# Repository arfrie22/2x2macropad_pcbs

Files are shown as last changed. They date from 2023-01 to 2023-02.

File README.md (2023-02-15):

# The PCBs for the 2x2 Macropad

This is a 2x2 Macropad with per-key RGB backlighting. It uses the RP2040 microcontroller and uses a custom firmware located at [https://github.com/arfrie22/2x2macropad_firmware](https://github.com/arfrie22/2x2macropad_firmware).

The PCBs are designed in KiCad

## Features

- Custom lighting effects
- Support for normal keys and media keys
- Keys can act as a key or used for a custom macro
- Up to 4 macros per key
- Customizable timing

## Building

The interactive BOM is can be viewed [here](https://htmlpreview.github.io/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).

There are 3 pcbs in this project:

- The main pcb, which contains all of the components
- The top plate, which holds the keyswitches
- The bottom plate, which protects the components

## Info

This project was created for a workshop hosted by the UMass All Campus Makerspace. The keyboard was designed to have as many parts as I could reasonably have be though-hole, while keeping the cost relativly low.

## Pictures
Macropad forwards with no rgb
Macropad backwards with rgb
Macropad rotated with rgb

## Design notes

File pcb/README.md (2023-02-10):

# Macropad pcb

## Images

### Front

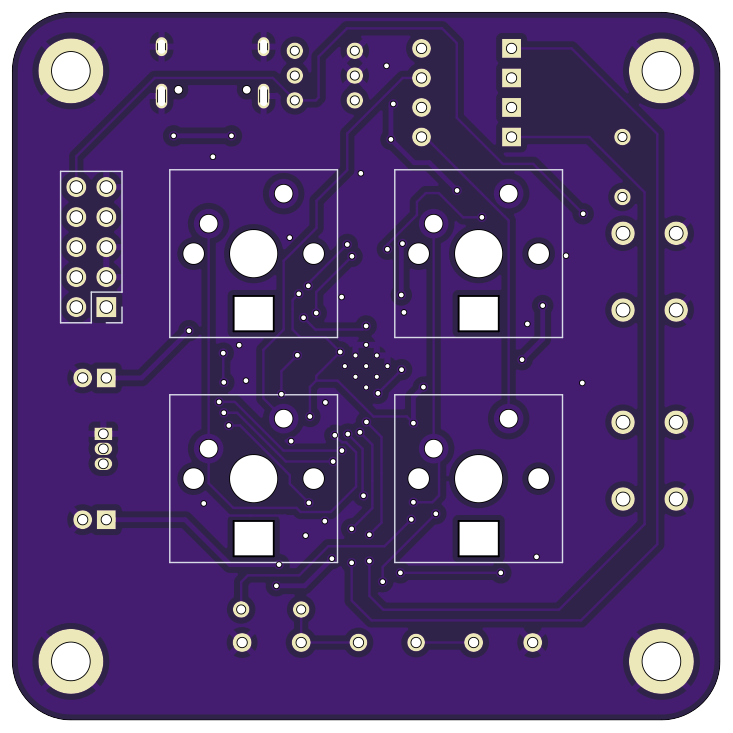
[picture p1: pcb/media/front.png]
Macropad pcb front


### Back

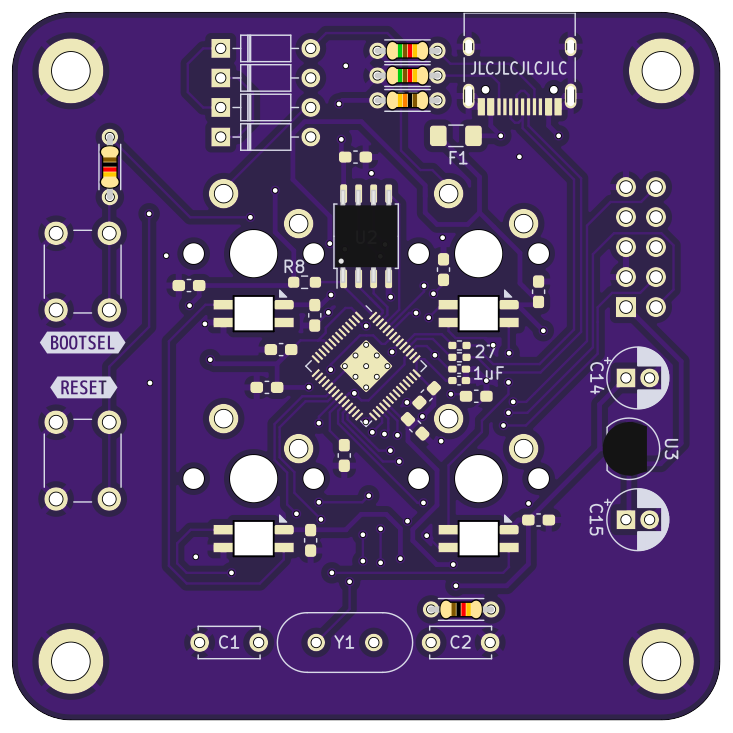
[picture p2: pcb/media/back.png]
Macropad pcb back


This is the main pcb for the 2x2 Macropad. Everything is on this pcb.
You can find the build instructions [here](https://htmlpreview.github.io/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).

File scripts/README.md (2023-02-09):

# Scripts for the project

This directory contains scripts for the project. These scripts are used to interact with kikit and pcbdraw.

## Scripts

- [plot.sh](plot.sh): Generates the images for the README.md files using pcbdraw
- [stencil.sh](stencil.sh): Generates the stencil and allignment jig files using kikit

## Dependencies

- [kikit](https://github.com/yaqwsx/KiKit)
- [pcbdraw](https://github.com/yaqwsx/PcbDraw)

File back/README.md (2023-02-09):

# Macropad back

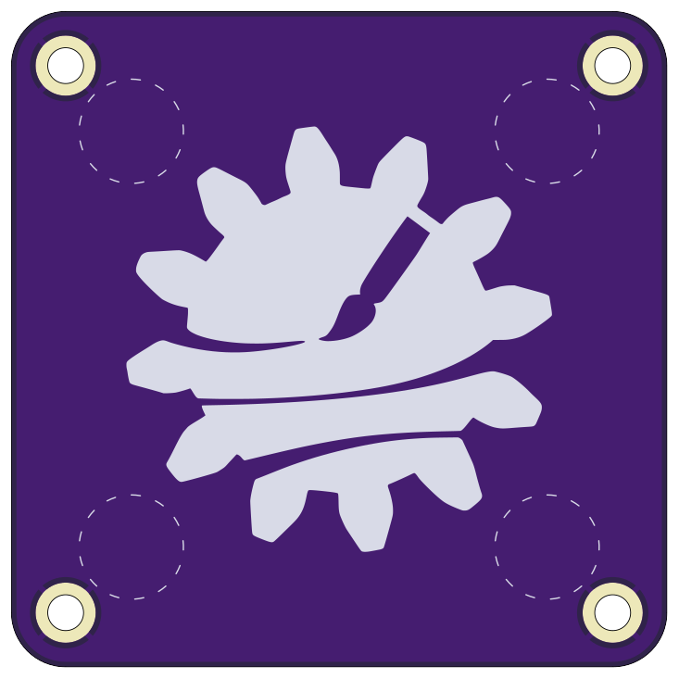
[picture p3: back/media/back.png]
Macropad back


This is the back of the macropad.

Nothing needs to be assembled

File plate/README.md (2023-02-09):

# Macropad plate

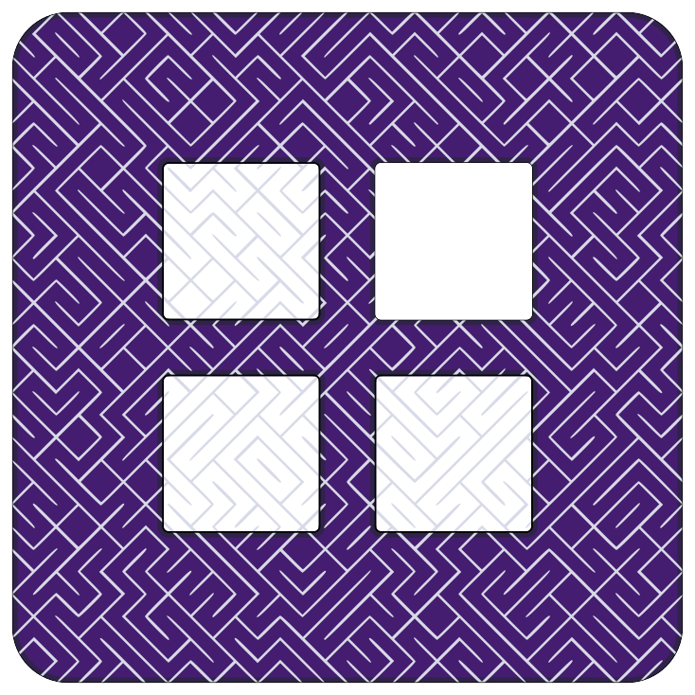
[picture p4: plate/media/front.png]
Macropad plate


This is the plate that holds the keyswitches.

Nothing needs to be assembled

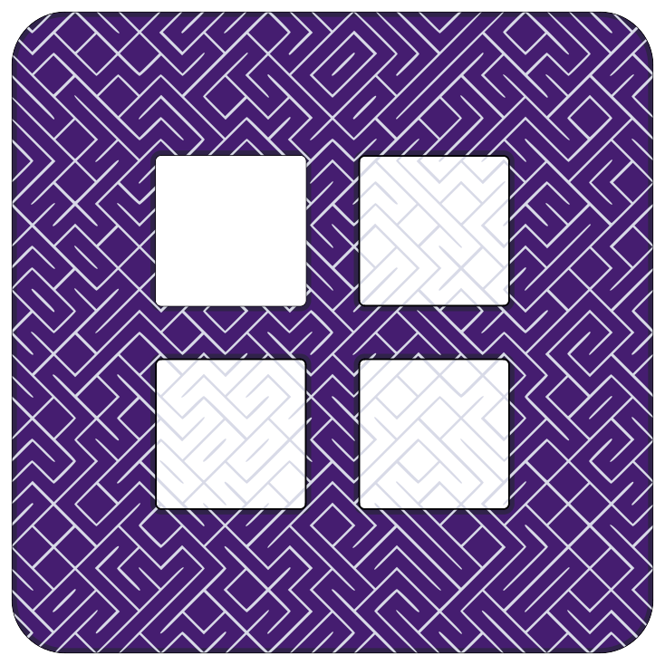
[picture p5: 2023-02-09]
plate/media/back.png

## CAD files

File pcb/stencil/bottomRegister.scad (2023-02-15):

// Generated by SolidPython 1.1.3 on 2023-02-13 22:43:17


scale(v = 0.0000010000) {
	translate(v = [-130000000, -130000000, 0]) {
		difference() {
			linear_extrude(convexity = 10, height = 2850000) {
				polygon(points = [[97000000.0000000000, 125762240.5374987423], [96996180.2977239937, 125913390.5052574873], [96984740.5116602331, 126064028.5974797755], [96965706.6532962620, 126213896.5919596255], [96939127.3132557571, 126362611.8978855163], [96905070.3446603566, 126509794.8670897037], [96863622.6899109036, 126655069.7632328868], [96814890.1587363183, 126798065.7210039198], [96758997.1580766439, 126938417.6928849071], [96696086.3744910806, 127075767.3810620308], [96626318.4099002779, 127209764.1521069556], [96549871.3715929985, 127340065.9320933074], [96466940.4175444692, 127466340.0798602998], [96377737.2582080364, 127588264.2361951321], [96282489.6160481274, 127705527.1467704773], [96181440.6441995949, 127817829.4567292184], [96074848.3057340533, 127924884.4748928398], [95962891.1387931257, 128026503.8414003402], [95886920.7662769109, 128092036.3354085833], [95886736.9051579833, 128092198.9126200974], [95759512.9314664453, 128207508.0010067970], [95759333.1155675352, 128207675.0414308310], [95733047.8039082885, 128232700.7385261506], [95732700.7385261506, 128233047.8039082885], [95707675.0414308310, 128259333.1155675352], [95707508.0010067970, 128259512.9314664453], [95592198.9126200974, 128386736.9051579833], [95592036.3354085833, 128386920.7662769109], [95568330.5419733971, 128414402.3688821197], [95568019.1661621928, 128414781.7814058512], [95545690.3857198805, 128443393.4693693072], [95545541.7746813446, 128443588.7922301888], [95443258.0611555576, 128581502.4148115218], [95443114.2883388549, 128581701.3259422630], [95422216.3128771931, 128611374.1712017059], [95421943.6253561974, 128611782.2769170254], [95402526.7999293208, 128642444.7949880213], [95402398.0494818240, 128642653.7437449545], [95314124.7588912696, 128789928.8316404969], [95314001.1750801802, 128790140.8771601319], [95296112.2765202522, 128821719.1993524879], [95295880.9034193903, 128822152.0679782331], [95279563.0276503861, 128854570.1193470657], [95279455.3777310997, 128854790.6817093194], [95206042.6301199049, 129010008.8953127414], [95205940.4254941046, 129010232.0331069976], [95191232.8837078214, 129043411.7157275826], [95191045.0532765090, 129043865.1785022765], [95177983.2772298753, 129077726.5596116930], [95177897.7645663917, 129077956.6114431173], [95120052.5648249090, 129239623.1145078689], [95119972.7236708105, 129239855.1956378073], [95108588.1803259403, 129274316.7002041638], [95108445.7014739215, 129274786.3900334090], [95098765.8171928674, 129309764.9972739518], [95098703.2653188705, 129310002.3230496645], [95056982.6943425238, 129476560.1787738949], [95056925.9855740815, 129476798.9681713581], [95048974.0800460279, 129512210.4115571678], [95048878.3249225318, 129512691.8050711304], [95042673.5549846143, 129548450.7753324807], [95042634.5663088560, 129548693.0894755274], [95017440.4160025716, 129718538.2546602637], [95017407.3857562244, 129718781.4526528269], [95012964.6992424577, 129754801.8032992482], [95012916.5900216699, 129755290.2644152492], [95010246.6897530854, 129791485.2192665190], [95010231.6397578120, 129791730.1881592423], [95001806.5435616970, 129963226.9610166550], [95001797.5099367946, 129963472.2254747003], [95000906.8279369473, 129999754.5877147764], [95000906.8279369473, 130000245.4122852236], [95001797.5099367946, 130036527.7745253295], [95001806.5435616970, 130036773.0389833748], [95010231.6397578120, 130208269.8118406534], [95010246.6897530854, 130208514.7807333767], [95012916.5900216699, 130244709.7355845422], [95012964.6992424577, 130245198.1967005432], [95017407.3857562840, 130281218.5473475605], [95017440.4160026312, 130281461.7453401238], [95042634.5663087964, 130451306.9105241001], [95042673.5549845546, 130451549.2246671468], [95048878.3249225765, 130487308.1949290484], [95048974.0800460726, 130487789.5884430110], [95056925.9855740964, 130523201.0318287015], [95056982.6943425387, 130523439.8212261647], [95098703.2653188705, 130689997.6769503355], [95098765.8171928674, 130690235.0027260482], [95108445.7014739215, 130725213.6099665910], [95108588.1803259403, 130725683.2997958362], [95119972.7236708105, 130760144.8043621927], [95120052.5648249090, 130760376.8854921311], [95177897.7645664662, 130922043.3885570914], [95177983.2772299498, 130922273.4403885156], [95191045.0532765538, 130956134.8214978576], [95191232.8837078661, 130956588.2842725515], [95205940.4254938662, 130989767.9668925107], [95206042.6301196665, 130989991.1046867669], [95279455.3777312338, 131145209.3182909787], [95279563.0276505202, 131145429.8806532323], [95295880.9034193307, 131177847.9320216924], [95296112.2765201926, 131178280.8006474376], [95314001.1750801057, 131209859.1228397787], [95314124.7588911951, 131210071.1683594137], [95402398.0494816750, 131357346.2562548220], [95402526.7999291867, 131357555.2050117552], [95421943.6253562123, 131388217.7230829597], [95422216.3128771782, 131388625.8287982643], [95443114.2883387804, 131418298.6740576476], [95443258.0611554980, 131418497.5851884037], [95545541.7746813446, 131556411.2077698112], [95545690.3857198805, 131556606.5306306928], [95568019.1661621928, 131585218.2185941488], [95568330.5419733971, 131585597.6311178803], [95592036.3354085833, 131613079.2337230891], [95592198.9126200974, 131613263.0948420167], [95707508.0010067970, 131740487.0685335547], [95707675.0414308310, 131740666.8844324648], [95732700.7385261506, 131766952.1960917115], [95733047.8039082885, 131767299.2614738494], [95759333.1155675352, 131792324.9585691690], [95759512.9314664453, 131792491.9989932030], [95886736.9051579833, 131907801.0873799026], [95886920.7662769109, 131907963.6645914167], [95962891.1387931257, 131973496.1585996598], [96074848.3057340533, 132075115.5251071602], [96181440.6441995949, 132182170.5432707816], [96282489.6160481274, 132294472.8532295227], [96377737.2582080364, 132411735.7638048679], [96466940.4175444692, 132533659.9201397002], [96549871.3715929985, 132659934.0679066926], [96626318.4099002779, 132790235.8478930444], [96696086.3744910806, 132924232.6189379692], [96758997.1580766439, 133061582.3071150929], [96814890.1587363183, 133201934.2789960802], [96863622.6899109036, 133344930.2367671132], [96905070.3446603566, 133490205.1329102963], [96939127.3132557571, 133637388.1021144837], [96965706.6532962620, 133786103.4080403745], [96984740.5116602331, 133935971.4025202245], [96996180.2977239937, 134086609.4947425127], [97000000.0000000000, 134237759.4625012577], [97000000.0000000000, 154983190.8553380966], [97000000.6278632730, 154983302.9127845466], [97000374.8108018786, 155016692.8798815608], [97000376.6943128705, 155016804.9232566953], [97006905.2673033178, 155308054.7890836596], [97006909.4315571487, 155308196.0209841728], [97008447.5638170391, 155350270.1459383667], [97008453.7231172323, 155350411.3049046695], [97014116.2972820103, 155462067.7529985011], [97014123.5145155489, 155462194.2235107720], [97016512.7726620734, 155499865.7805950046], [97016521.5913657695, 155499992.1495365798], [97032871.7751336396, 155714693.9899461865], [97032882.1938923448, 155714820.2370388508], [97036225.0080600977, 155752419.1779938638], [97036237.0252019465, 155752545.2829788327], [97047769.4693838507, 155865953.0643368661], [97047783.0829804540, 155866079.0069782436], [97052077.3075863123, 155903581.1989485323], [97052092.5154531300, 155903706.9590364993], [97079296.1836424470, 156117305.1079567373], [97079312.9833390564, 156117430.6653106809], [97084555.8621373177, 156154812.0375349820], [97084574.2509679347, 156154937.3720068634], [97101835.9032062441, 156267615.4865793884], [97101855.8782199919, 156267740.5780569613], [97108044.0460721850, 156304977.1373250484], [97108065.6040637344, 156305101.9657350183], [97146052.9252479672, 156517048.1197777987], [97146076.0627579242, 156517172.6650891006], [97153205.5477924496, 156554240.5111387968], [97153230.2611079514, 156554364.7533657849], [97176176.8109884113, 156666023.9580457509], [97176203.0961437374, 156666147.8772514462], [97184269.3223042786, 156703023.2181047499], [97184297.1750815213, 156703146.7944040000], [97232970.6363524497, 156912896.8908343911], [97233000.0522820652, 156913020.1043970287], [97241997.8422666490, 156949679.2716405690], [97242028.8166283220, 156949802.1026946902], [97270601.3606869876, 157060155.7699077129], [97270633.8885102868, 157060278.1987427473], [97280557.4670922011, 157096697.6627095640], [97280591.5431574434, 157096819.6696794927], [97339826.2004377544, 157303835.2830067873], [97339861.8192767799, 157303956.8485333025], [97350704.8170139790, 157340113.2334156036], [97350741.9729110748, 157340234.3379912674], [97384867.1658362597, 157448999.1914533377], [97384905.8528290689, 157449119.8156446218], [97396661.3101493269, 157484989.9144860506], [97396701.5220298022, 157485110.0389365256], [97466345.3208038956, 157688859.7630508542],
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

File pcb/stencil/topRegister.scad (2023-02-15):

// Generated by SolidPython 1.1.3 on 2023-02-13 22:43:01


scale(v = 0.0000010000) {
	translate(v = [-130000000, -130000000, 0]) {
		difference() {
			linear_extrude(convexity = 10, height = 2850000) {
				polygon(points = [[163000000.0000000000, 125762240.5374987423], [163003819.7022759914, 125913390.5052574873], [163015259.4883397818, 126064028.5974797755], [163034293.3467037380, 126213896.5919596255], [163060872.6867442429, 126362611.8978855163], [163094929.6553396583, 126509794.8670897037], [163136377.3100891113, 126655069.7632328868], [163185109.8412636817, 126798065.7210039198], [163241002.8419233561, 126938417.6928849071], [163303913.6255089045, 127075767.3810620308], [163373681.5900997221, 127209764.1521069556], [163450128.6284070015, 127340065.9320933074], [163533059.5824555159, 127466340.0798602998], [163622262.7417919636, 127588264.2361951321], [163717510.3839518726, 127705527.1467704773], [163818559.3558003902, 127817829.4567292184], [163925151.6942659616, 127924884.4748928398], [164037108.8612068892, 128026503.8414003402], [164113079.2337231040, 128092036.3354085833], [164113263.0948420167, 128092198.9126200974], [164240487.0685335398, 128207508.0010067970], [164240666.8844324648, 128207675.0414308310], [164266952.1960917115, 128232700.7385261506], [164267299.2614738345, 128233047.8039082885], [164292324.9585691690, 128259333.1155675352], [164292491.9989932179, 128259512.9314664453], [164407801.0873799026, 128386736.9051579833], [164407963.6645914316, 128386920.7662769109], [164431669.4580265880, 128414402.3688821197], [164431980.8338378072, 128414781.7814058512], [164454309.6142801046, 128443393.4693693072], [164454458.2253186703, 128443588.7922301888], [164556741.9388444424, 128581502.4148115218], [164556885.7116611600, 128581701.3259422630], [164577783.6871228218, 128611374.1712017059], [164578056.3746438026, 128611782.2769170254], [164597473.2000706792, 128642444.7949880213], [164597601.9505181909, 128642653.7437449545], [164685875.2411087155, 128789928.8316404969], [164685998.8249198198, 128790140.8771601319], [164703887.7234797478, 128821719.1993524879], [164704119.0965806246, 128822152.0679782331], [164720436.9723496139, 128854570.1193470657], [164720544.6222689152, 128854790.6817093194], [164793957.3698800802, 129010008.8953127414], [164794059.5745058954, 129010232.0331069976], [164808767.1162921786, 129043411.7157275826], [164808954.9467234910, 129043865.1785022765], [164822016.7227701247, 129077726.5596116930], [164822102.2354336083, 129077956.6114431173], [164879947.4351750910, 129239623.1145078689], [164880027.2763291895, 129239855.1956378073], [164891411.8196740746, 129274316.7002041638], [164891554.2985260785, 129274786.3900334090], [164901234.1828071475, 129309764.9972739518], [164901296.7346811295, 129310002.3230496645], [164943017.3056574762, 129476560.1787738949], [164943074.0144259334, 129476798.9681713581], [164951025.9199539721, 129512210.4115571678], [164951121.6750774682, 129512691.8050711304], [164957326.4450153708, 129548450.7753324807], [164957365.4336911440, 129548693.0894755274], [164982559.5839974284, 129718538.2546602637], [164982592.6142437756, 129718781.4526528269], [164987035.3007575274, 129754801.8032992482], [164987083.4099783301, 129755290.2644152492], [164989753.3102469146, 129791485.2192665190], [164989768.3602421880, 129791730.1881592423], [164998193.4564383030, 129963226.9610166550], [164998202.4900631905, 129963472.2254747003], [164999093.1720630527, 129999754.5877147764], [164999093.1720630527, 130000245.4122852236], [164998202.4900631905, 130036527.7745253295], [164998193.4564383030, 130036773.0389833748], [164989768.3602421880, 130208269.8118406534], [164989753.3102469146, 130208514.7807333767], [164987083.4099783301, 130244709.7355845422], [164987035.3007575274, 130245198.1967005432], [164982592.6142437160, 130281218.5473475605], [164982559.5839973688, 130281461.7453401238], [164957365.4336912036, 130451306.9105241001], [164957326.4450154305, 130451549.2246671468], [164951121.6750774384, 130487308.1949290484], [164951025.9199539423, 130487789.5884430110], [164943074.0144259036, 130523201.0318287015], [164943017.3056574464, 130523439.8212261647], [164901296.7346811295, 130689997.6769503355], [164901234.1828071475, 130690235.0027260482], [164891554.2985260785, 130725213.6099665910], [164891411.8196740746, 130725683.2997958362], [164880027.2763291895, 130760144.8043621927], [164879947.4351750910, 130760376.8854921311], [164822102.2354335189, 130922043.3885570914], [164822016.7227700353, 130922273.4403885156], [164808954.9467234612, 130956134.8214978576], [164808767.1162921190, 130956588.2842725515], [164794059.5745061338, 130989767.9668925107], [164793957.3698803186, 130989991.1046867669], [164720544.6222687662, 131145209.3182909787], [164720436.9723494649, 131145429.8806532323], [164704119.0965806842, 131177847.9320216924], [164703887.7234798074, 131178280.8006474376], [164685998.8249198794, 131209859.1228397787], [164685875.2411088049, 131210071.1683594137], [164597601.9505183101, 131357346.2562548220], [164597473.2000707984, 131357555.2050117552], [164578056.3746438026, 131388217.7230829597], [164577783.6871228218, 131388625.8287982643], [164556885.7116612196, 131418298.6740576476], [164556741.9388445020, 131418497.5851884037], [164454458.2253186703, 131556411.2077698112], [164454309.6142801046, 131556606.5306306928], [164431980.8338378072, 131585218.2185941488], [164431669.4580265880, 131585597.6311178803], [164407963.6645914316, 131613079.2337230891], [164407801.0873799026, 131613263.0948420167], [164292491.9989932179, 131740487.0685335547], [164292324.9585691690, 131740666.8844324648], [164267299.2614738345, 131766952.1960917115], [164266952.1960917115, 131767299.2614738494], [164240666.8844324648, 131792324.9585691690], [164240487.0685335398, 131792491.9989932030], [164113263.0948420167, 131907801.0873799026], [164113079.2337231040, 131907963.6645914167], [164037108.8612068892, 131973496.1585996598], [163925151.6942659616, 132075115.5251071602], [163818559.3558003902, 132182170.5432707816], [163717510.3839518726, 132294472.8532295227], [163622262.7417919636, 132411735.7638048679], [163533059.5824555159, 132533659.9201397002], [163450128.6284070015, 132659934.0679066926], [163373681.5900997221, 132790235.8478930444], [163303913.6255089045, 132924232.6189379692], [163241002.8419233561, 133061582.3071150929], [163185109.8412636817, 133201934.2789960802], [163136377.3100891113, 133344930.2367671132], [163094929.6553396583, 133490205.1329102963], [163060872.6867442429, 133637388.1021144837], [163034293.3467037380, 133786103.4080403745], [163015259.4883397818, 133935971.4025202245], [163003819.7022759914, 134086609.4947425127], [163000000.0000000000, 134237759.4625012577], [163000000.0000000000, 154983190.8553380966], [162999999.3721367121, 154983302.9127845466], [162999625.1891981363, 155016692.8798815608], [162999623.3056871295, 155016804.9232566953], [162993094.7326966822, 155308054.7890836596], [162993090.5684428513, 155308196.0209841728], [162991552.4361829758, 155350270.1459383667], [162991546.2768827677, 155350411.3049046695], [162985883.7027179897, 155462067.7529985011], [162985876.4854844511, 155462194.2235107720], [162983487.2273379266, 155499865.7805950046], [162983478.4086342454, 155499992.1495365798], [162967128.2248663604, 155714693.9899461865], [162967117.8061076403, 155714820.2370388508], [162963774.9919399023, 155752419.1779938638], [162963762.9747980535, 155752545.2829788327], [162952230.5306161642, 155865953.0643368661], [162952216.9170195460, 155866079.0069782436], [162947922.6924136877, 155903581.1989485323], [162947907.4845468700, 155903706.9590364993], [162920703.8163575530, 156117305.1079567373], [162920687.0166609287, 156117430.6653106809], [162915444.1378626823, 156154812.0375349820], [162915425.7490320802, 156154937.3720068634], [162898164.0967937708, 156267615.4865793884], [162898144.1217800081, 156267740.5780569613], [162891955.9539278150, 156304977.1373250484], [162891934.3959362507, 156305101.9657350183], [162853947.0747520328, 156517048.1197777987], [162853923.9372420907, 156517172.6650891006], [162846794.4522075653, 156554240.5111387968], [162846769.7388920486, 156554364.7533657849], [162823823.1890115738, 156666023.9580457509], [162823796.9038562775, 156666147.8772514462], [162815730.6776957214, 156703023.2181047499], [162815702.8249184787, 156703146.7944040000], [162767029.3636475503, 156912896.8908343911], [162766999.9477179348, 156913020.1043970287], [162758002.1577333510, 156949679.2716405690], [162757971.1833716631, 156949802.1026946902], [162729398.6393130124, 157060155.7699077129], [162729366.1114897132, 157060278.1987427473], [162719442.5329077840, 157096697.6627095640], [162719408.4568425417, 157096819.6696794927], [162660173.7995622456, 157303835.2830067873], [162660138.1807232201, 157303956.8485333025], [162649295.1829860210, 157340113.2334156036], [162649258.0270889401, 157340234.3379912674], [162615132.8341637254,
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

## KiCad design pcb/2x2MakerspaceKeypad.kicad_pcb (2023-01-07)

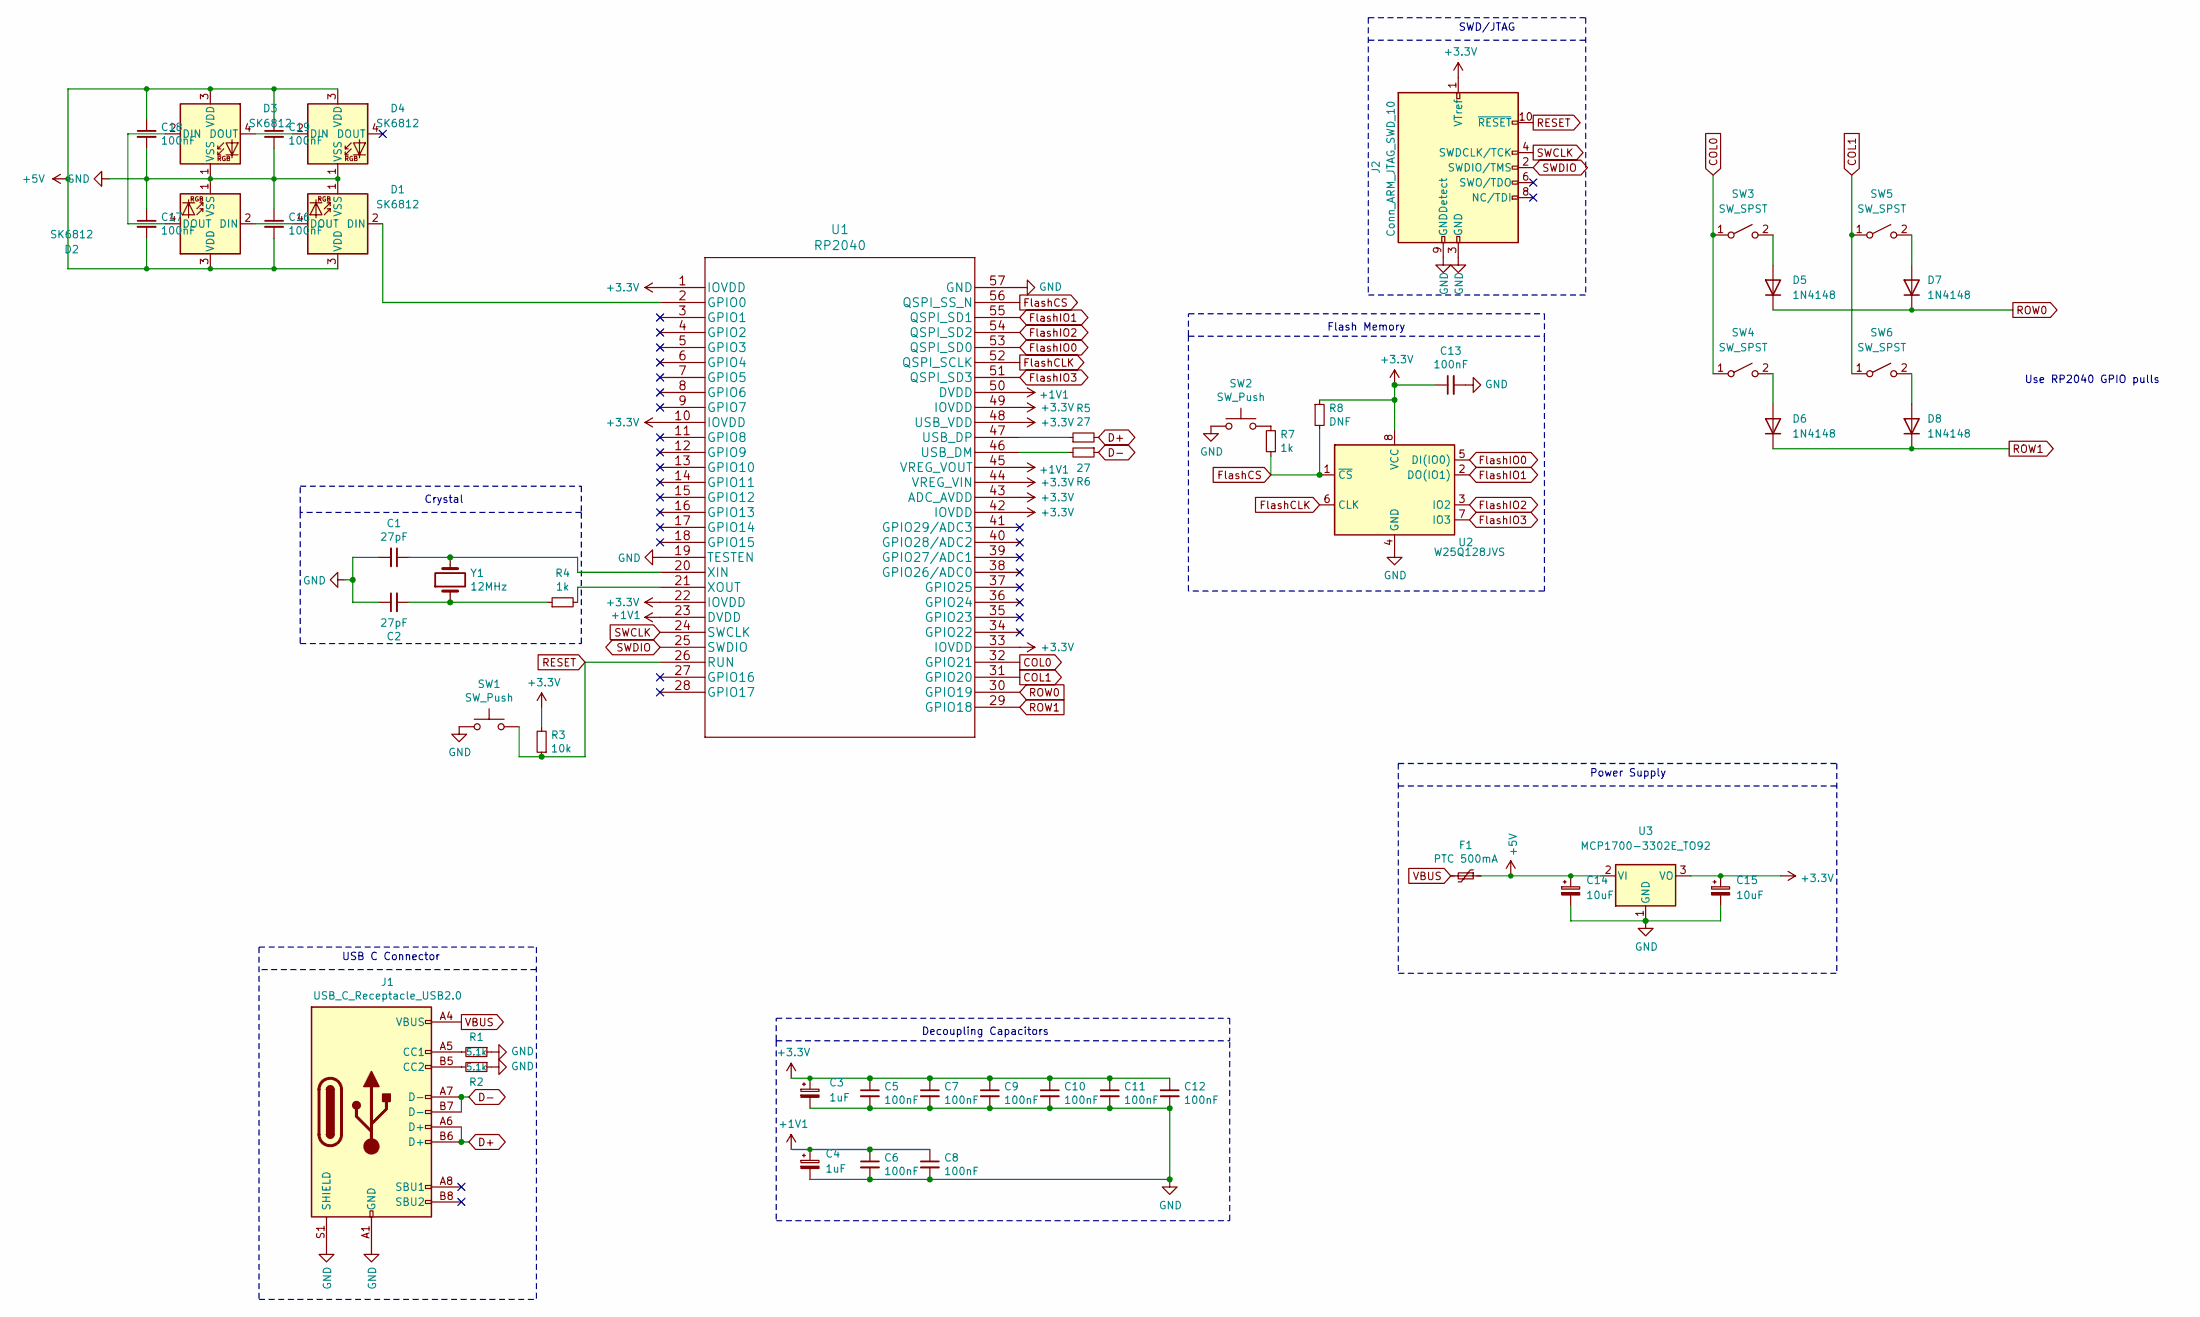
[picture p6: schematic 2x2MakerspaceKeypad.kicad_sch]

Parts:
C1, C2: 27pF; C_Disc_D5.0mm_W2.5mm_P5.00mm
C3, C4: 1uF; C_0402_1005Metric_Pad0.74x0.62mm_HandSolder
C5, C6, C7, C8, C9, C10, C11, C12, C13, C16, C17, C18, C19: 100nF; C_0603_1608Metric_Pad1.08x0.95mm_HandSolder
C14, C15: 10uF; CP_Radial_D5.0mm_P2.00mm
D1, D2, D3, D4: SK6812; SK6812-MINI-E-mx
D5, D6, D7, D8: 1N4148; D_DO-35_SOD27_P7.62mm_Horizontal
F1: PTC 500mA; Fuse_1206_3216Metric_Pad1.42x1.75mm_HandSolder
J1: USB_C_Receptacle_USB2.0; USB_C_Receptacle_HRO_TYPE-C-31-M-12
J2: Conn_ARM_JTAG_SWD_10; PinHeader_2x05_P2.54mm_Vertical
R1, R2: 5.1k; R_Axial_DIN0204_L3.6mm_D1.6mm_P5.08mm_Horizontal
R3: 10k; R_Axial_DIN0204_L3.6mm_D1.6mm_P5.08mm_Horizontal
R4, R7: 1k; R_Axial_DIN0204_L3.6mm_D1.6mm_P5.08mm_Horizontal
R5, R6: 27; R_0402_1005Metric_Pad0.72x0.64mm_HandSolder
R8: DNF; R_0603_1608Metric_Pad0.98x0.95mm_HandSolder
SW1, SW2: SW_Push; SW_PUSH_6mm_H5mm
SW3, SW4, SW5, SW6: SW_SPST; SW_Cherry_MX_PCB_1.00u
U1: RP2040; RP2040-QFN-56
U2: W25Q128JVS; SOIC-8_5.23x5.23mm_P1.27mm
U3: MCP1700-3302E_TO92; TO-92_Inline
Y1: 12MHz; Crystal_HC49-4H_Vertical

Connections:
+1V1: C4.1, C6.1, C8.1, U1.23 (DVDD), U1.45 (VREG_VOUT), U1.50 (DVDD)
+3V3: C3.1, C5.1, C7.1, C9.1, C10.1, C11.1, C12.1, C13.1, C15.1, J2.1 (VTref), R3.2, R8.1, U1.1 (IOVDD), U1.10 (IOVDD), U1.22 (IOVDD), U1.33 (IOVDD), U1.42 (IOVDD), U1.43 (ADC_AVDD), U1.44 (VREG_VIN), U1.48 (USB_VDD), U1.49 (IOVDD), U2.8 (VCC), U3.3 (VO)
+5V: C14.1, C16.2, C17.2, C18.1, C19.1, D1.3 (VDD), D2.3 (VDD), D3.3 (VDD), D4.3 (VDD), F1.1, U3.2 (VI)
COL0: SW3.1 (A), SW4.1 (A), U1.32 (GPIO21)
COL1: SW5.1 (A), SW6.1 (A), U1.31 (GPIO20)
D+: J1.A6 (D+), J1.B6 (D+), R5.2
D-: J1.A7 (D-), J1.B7 (D-), R6.1
FlashCLK: U1.52 (QSPI_SCLK), U2.6 (CLK)
FlashCS: R7.1, R8.2, U1.56 (QSPI_SS_N), U2.1 (~CS)
FlashIO0: U1.53 (QSPI_SD0), U2.5 (DI(IO0))
FlashIO1: U1.55 (QSPI_SD1), U2.2 (DO(IO1))
FlashIO2: U1.54 (QSPI_SD2), U2.3 (IO2)
FlashIO3: U1.51 (QSPI_SD3), U2.7 (IO3)
GND: C1.2, C2.1, C3.2, C4.2, C5.2, C6.2, C7.2, C8.2, C9.2, C10.2, C11.2, C12.2, C13.2, C14.2, C15.2, C16.1, C17.1, C18.2, C19.2, D1.1 (VSS), D2.1 (VSS), D3.1 (VSS), D4.1 (VSS), J1.A1 (GND), J1.A12 (GND), J1.B1 (GND), J1.B12 (GND), J1.S1 (SHIELD), J2.3 (GND), J2.5 (GND), J2.9 (GNDDetect), R1.1, R2.1, SW1.1, SW2.1, U1.19 (TESTEN), U1.57 (GND), U2.4 (GND), U3.1 (GND)
unnamed: C1.1, U1.20 (XIN), Y1.2
unnamed: C2.2, R4.1, Y1.1
unnamed: D1.2 (DIN), U1.2 (GPIO0)
unnamed: D1.4 (DOUT), D2.2 (DIN)
unnamed: D2.4 (DOUT), D3.2 (DIN)
unnamed: D3.4 (DOUT), D4.2 (DIN)
unnamed: D5.2 (A), SW3.2 (B)
unnamed: D6.2 (A), SW4.2 (B)
unnamed: D7.2 (A), SW5.2 (B)
unnamed: D8.2 (A), SW6.2 (B)
unnamed: J1.A5 (CC1), R1.2
unnamed: J1.B5 (CC2), R2.2
unnamed: R4.2, U1.21 (XOUT)
unnamed: R5.1, U1.47 (USB_DP)
unnamed: R6.2, U1.46 (USB_DM)
unnamed: R7.2, SW2.2
RESET: J2.10 (~RESET), R3.1, SW1.2, U1.26 (RUN)
ROW0: D5.1 (K), D7.1 (K), U1.30 (GPIO19)
ROW1: D6.1 (K), D8.1 (K), U1.29 (GPIO18)
SWCLK: J2.4 (SWDCLK/TCK), U1.24 (SWCLK)
SWDIO: J2.2 (SWDIO/TMS), U1.25 (SWDIO)
VBUS: F1.2, J1.A4 (VBUS), J1.A9 (VBUS), J1.B4 (VBUS), J1.B9 (VBUS)

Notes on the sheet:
Crystal
SWD/JTAG
USB C Connector
Use RP2040 GPIO pulls
Flash Memory
Decoupling Capacitors
Power Supply

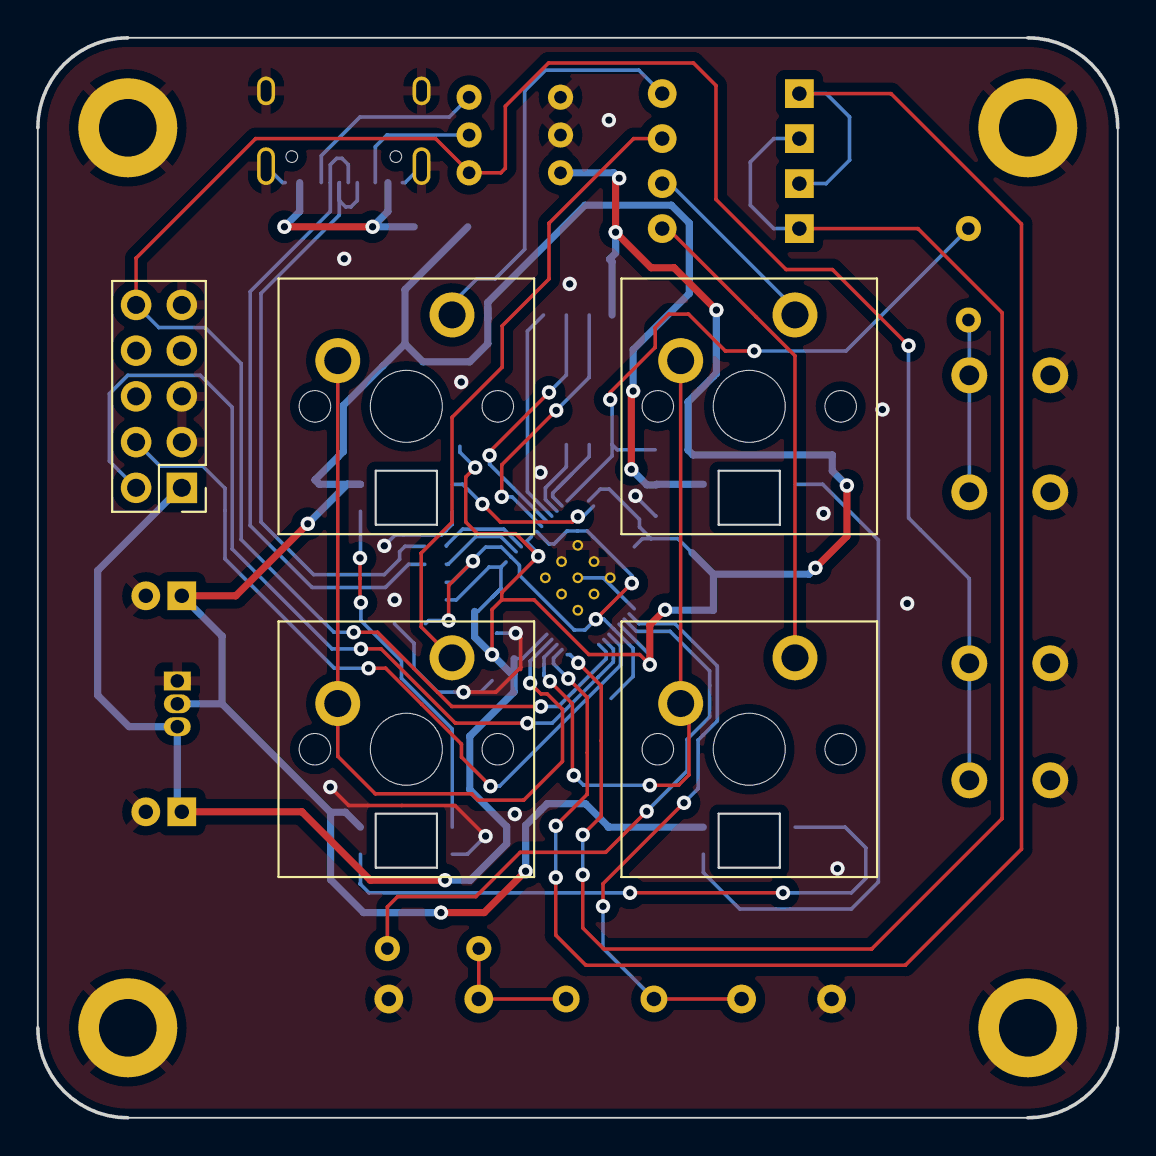
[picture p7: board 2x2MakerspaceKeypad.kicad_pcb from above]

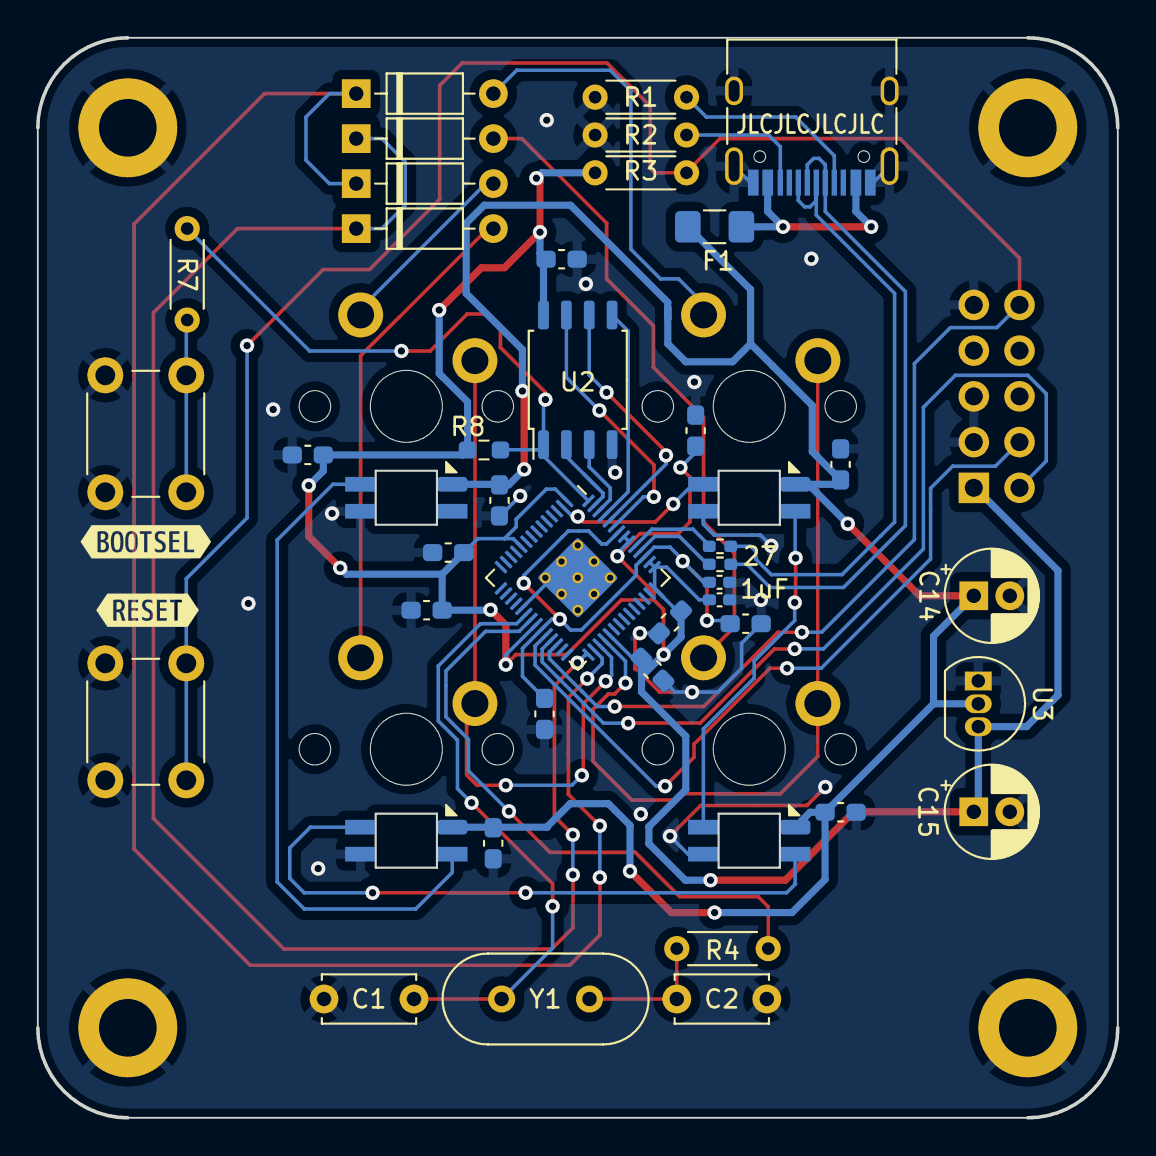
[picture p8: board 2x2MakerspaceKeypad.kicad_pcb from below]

Board: 2 copper layers, 60.0 x 60.0 mm, 50 parts (45 on the bottom side), 36 nets.

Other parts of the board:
kibuzzard-6390E1A9: G***; kibuzzard-6390E1A9
kibuzzard-6390E1BA: G***; kibuzzard-6390E1BA

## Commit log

2023-01-07 Added macropad v2
    [2x2MakerspaceBack.kicad_pcb, 2x2MakerspaceBack.kicad_sch, 2x2MakerspaceKeypad.kicad_pcb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]
2023-02-09 Added readme + kikit files
    [2x2MakerspacePlate.kicad_pcb, bottomRegister.scad, stencil.kicad_pcb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]
2023-02-10 added bom
2023-02-15 Updated stencil jig
    [bottomRegister.scad, stencil.kicad_pcb, topRegister.scad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]
